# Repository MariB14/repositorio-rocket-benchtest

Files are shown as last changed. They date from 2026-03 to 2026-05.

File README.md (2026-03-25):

# Bench test stand "Maria"
## Objective
Design and manufacture of an instrument for measuring propulsion parameters for rocket motor class H to K with short funds and accesible materials.

## Keywords
* "Rocket motor testing"
* "Low-cost instrumentation"
* "Thrust measurement"
* "Truss analysis"
* "Pressure measurement"

## Particular objectives
* Restrictions of desired parameters to measure (maximum and minimums)
* Statistic sounding and research
* Cost analysis of material and sensors 
* Sensors involved and individual test
* Data logging of parameters individually
* Fusion of sensors and data sampling coupling of frequency
* Data logging fusion
* Power electronics of data logging and sensing
* Strucutral analysis proposal in function of restrictions
* Conceptual design and materials designation
* In-depth design of benchtest 
* Assembly and manufacturing considerations
* Quality control across manufacture
* Process sheet of manufacturing
* Quality assurance of manufacture
* Operations sheet procedure
* Redaction of Manual Of Use

## Research websites
* https://www.sciencedirect.com/
* https://link.springer.com/
* https://onlinelibrary.wiley.com/
* https://iopscience.iop.org/journalList
* https://www.ieee.org/
* https://www.tandfonline.com/
* https://pubs.acs.org/
* https://www.aps.org/

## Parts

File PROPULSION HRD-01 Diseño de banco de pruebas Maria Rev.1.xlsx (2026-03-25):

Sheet: Overview
 |  | (Materials selection in mechanical design, pp 12)
Design process for the structural components of the Rocket Bench stand |  |  | Concepto
 |  |  | Maxima carga de 300 kg en el eje horizontal (x)
1. Exhaustive analysis of loads |  |  | Viabilidad de lectura de perturbaciones en los tres ejes (x,y,z)
 | a. Permanent loads |  | Referencias | https://www.researchgate.net/publication/323685633_Design_and_Implementation_of_a_Thrust_Vector_Control_TVC_Test_System
 | b. Variable loads |  | Historial de proyectos similares
2. Overview of materials |  |  | Transportable maximo 20kg por ensamble completo sin motor
 | a. Characteristics for tension, compresion and flexion |  | Restriccion de costo $1,500 MXN
 | b. Variable and static loads capabilities |  | Elevado margen de seguridad (s.f. 2 - 3)
 | c. Corrosion and termal properties |  | Diseño por funcionalidad y analisis de cargas y apoyos
3. Predimension process taking into account step 2 and step 3 |  |  | Diseño de nodos para analisis de truss/armadura a maxima carga de medicion (300kg)
 | a. Design process |  | y perturbaciones del 20% de la maxima carga, demostracion de porcentaje en hoja de
 | b. Loads overview |  | armadura.
 | c. Materials asignation due to loads and geometry
 | d. Aesthetics
4. Structural analysis
 | a. Known materials properties
 | b. Loads conditions
 | c. Standards and normative
5. Simulations
 | a. FEM
 | b. Vibrations and fatigue
6. Drawings and tolerances
7. Tracking of structure, due to failure when it's used
8. Quality assurance
 | a. Calendar of use, manual register

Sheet: PTR base data
PTR cuadrado (Perfil Tubular Rectangular) | Calibre | Espesor (in) | Largo | Pieza x paquete | kg/m | Norma | Referencias de normas
1/2″ x 1/2″ | 20 | 0.036 | 6 | 231 | 0.34 | A513 | ASTM A513 | https://www.materiales.gelsonluz.com/2020/09/astm-a513-propiedades-mecanicas.html | A500B | ASTM A500 Grade B Specifications | American Standard Steel Products (nan-steel.com) (https://www.nan-steel.com/news/astm-a500-grade-b.html)
 | 18 | 0.048 | 6 | 231 | 0.44 | A513
5/8″ x 5/8″ | 20 | 0.036 | 6 | 252 | 0.43 | A513 | Referencia | PTR - Perfiles estructurales (fortacero.com) (https://www.fortacero.com/cat_ptr/)
 | 18 | 0.048 | 6 | 252 | 0.56 | A513
3/4″ x 3/4″ | 20 | 0.036 | 6 | 121 | 0.52 | A513
 | 18 | 0.048 | 6 | 121 | 0.68 | A513
 | 16 | 0.06 | 6 | 121 | 0.84 | A513
 | 14 | 0.075 | 6 | 121 | 1.02 | A513
1″ x 1″ | 20 | 0.036 | 6 | 100 | 0.7 | A513
 | 18 | 0.048 | 6 | 100 | 0.92 | A513
 | 16 | 0.06 | 6 | 100 | 1.14 | A513
 | 14 | 0.075 | 6 | 100 | 1.4 | A513
 | 13 | 0.09 | 6 | 100 | 1.65 | A513
 | 12 | 0.105 | 6 | 100 | 1.9 | A513
 | 11 | 0.12 | 6 | 100 | 1.94 | A500°B
 | 10 | 0.135 | 6 | 100 | 2.12 | A500°B
1 1/4″ x 1 1/4″ | 20 | 0.036 | 6 | 81 | 0.88 | A513
 | 18 | 0.0485 | 6 | 81 | 1.16 | A513
 | 16 | 0.06 | 6 | 100 | 1.44 | A513
 | 14 | 0.075 | 6 | 100 | 1.78 | A513
 | 12 | 0.105 | 6 | 100 | 2.42 | A513
1 1/2″ x 1 1/2″ | 20 | 0.036 | 6 | 49 | 1.06 | A513
 | 18 | 0.048 | 6 | 49 | 1.4 | A513
 | 16 | 0.06 | 6 | 100 | 1.74 | A513
 | 14 | 0.075 | 6 | 64 | 2.15 | A513
 | 12 | 0.105 | 6 | 64 | 2.95 | A513
 | 9 | 0.15 | 6 | 64 | 3.79 | A500°B
2″ x 2″ | 18 | 0.048 | 6 | 64 | 1.89 | A513
 | 14 | 0.075 | 6 | 64 | 2.91 | A513
 | 12 | 0.105 | 6 | 64 | 4.01 | A513
 | 10 | 0.135 | 6 | 64 | 4.84 | A500°B
 | 9 | 0.15 | 6 | 64 | 5.31 | A513
2 1/2″ x 2 1/2″ | 14 | 0.075 | 6 | 42 | 3.67 | A513
 | 11 | 0.12 | 6 | 36 | 5.57 | A500°B
 | 7 | 0.18 | 6.1 | 36 | 8.34 | A500°B
 | 1/4″ | 0.25 | 6.1 | 36 | 10.57 | A500°B
3″ x 3″ | 14 | 0.075 | 6 | 42 | 4.42 | A513
 | 11 | 0.12 | 6.10/ 12.20 | 36 | 6.78 | A500°B
 | 9 | 0.15 | 6.1 | 25 | 8.33 | A500°B
 | 7 | 0.18 | 6.1 | 25 | 10.24 | A500°B
 | 1/4″ | 0.25 | 6.10/ 12.20 | 25 | 13.1 | A500°B
3 1/2″ x 3 1/2″ | 11 | 0.12 | 6.1 | 36 | 7.99 | A500°B
 | 9 | 0.15 | 6.1 | 25 | 9.85 | A500°B
 | 7 | 0.18 | 6.1 | 25 | 12.14 | A500°B
 | 1/4″ | 0.25 | 6.10/12.20 | 16 | 15.63 | A500°B
4″ x 4″ | 14 | 0.075 | 6 | 30 | 5.93 | A513
 | 1/8″ | 0.125 | 6.10/12.20 | 30 | 9.21 | A500°B
 | 9 | 0.15 | 6.1 | 25 | 11.36 | A500°B
 | 3/16″ | 0.187 | 6.10/12.20 | 25 | 14.04 | A500°B
 | 1/4″ | 0.25 | 6.10/ 12.20 | 16 | 18.16 | A500°B
5″ x 5″ | 1/8″ | 0.125 | 6.10/12.20 | 20 | 11.63 | A500°B
 | 3/16″ | 0.187 | 6.10/12.20 | 16 | 18.96 | A500°B
 | 1/4″ | 0.25 | 6.10/12.20 | 12 | 23.22 | A500°B
PTR rectangular | Calibre | Espesor (in) | Largo | Pieza x paquete | kg/m | Norma
1″ x1/2″ | 18 | 0.048 | 6 | 120 | 0.68 | A513
1 1/4″ x 3/4″ | 20 | 0.036 | 6 | 99 | 0.7 | A513
 | 18 | 0.048 | 6 | 99 | 0.92 | A513
1 1/2″ x 1/2″ | 20 | 0.036 | 6 | 98 | 0.7 | A513
 | 18 | 0.048 | 6 | 98 | 0.92 | A513
1/2″ x 1″ | 20 | 0.036 | 6 | 84 | 0.88 | A513
 | 18 | 0.048 | 6 | 84 | 1.16 | A513
 | 16 | 0.06 | 6 | 100 | 1.44 | A513
 | 14 | 0.075 | 6 | 84 | 1.78 | A513
 | 11 | 0.12 | 6 | 63 | 2.55 | A513
1 3/4″» x 3/4″ | 20 | 0.036 | 6 | 84 | 0.88 | A513
 | 18 | 0.048 | 6 | 84 | 1.16 | A513
2″ x 1″ | 20 | 0.036 | 6 | 50 | 1.06 | A513
 | 18 | 0.048 | 6 | 50 | 1.4 | A513
 | 14 | 0.075 | 6 | 80 | 2.15 | A513
 | 11 | 0.12 | 6 | 80 | 3.15 | A500°B
2 1/4″ x 3/4″ | 20 | 0.036 | 6 | 55 | 1.06 | A513
 | 18 | 0.048 | 6 | 55 | 1.4 | A513
2 1/2″ x 1 1/4″ | 20 | 0.075 | 6 | 54 | 1.34 | A513
 | 18 | 0.075 | 6 | 54 | 1.77 | A513
 | 14 | 0.075 | 6 | – | – | A513
2 1/2″» x 1 1/2″ | 14 | 0.075 | 6 | 48 | 2.91 | A513
3″ x 1″ | 18 | 0.048 | 6 | 48 | 1.89 | A513
 | 16 | 0.06 | 6 | 48 | 2.35 | A513
 | 14 | 0.075 | 6 | 48 | 2.91 | A513
 | 11 | 0.12 | 6 | 48 | 4.36 | A513
 | 10 | 0.135 | 6 | 48 |  | A513
3″ x 1 1/2″ | 20 | 0.036 | 6 | 48 | 1.61 | A513
 | 18 | 0.048 | 6 | 70 | 2.13 | A513
 | 14 | 0.075 | 6 | 70 | 3.29 | A513
 | 11 | 0.12 | 6 | 70 | 4.9 | A500°B
3″ x 2″ | 14 | 0.075 | 6 | 49 | 3.67 | A513
 | 11 | 0.12 | 6 | 42 | 5.57 | A500°B
 | 10 | 0.135 | 6 | 42 | 6.2 | A500°B
 | 7 | 0.18 | 6.1 | 36 | 8.34 | A500°B
 | 1/4″ | 0.25 | 6.1 | 36 | 10.57 | A500°B
4″ x 1 1/2″ | 14 | 0.075 | 6 | 35 | 4.04 | A513
4″ x 2″ | 14 | 0.075 | 6.1 | 40 | 4.42 | A513
 | 11 | 0.12 | 6.1 | 32 | 6.78 | A500°B
 | 9 | 0.15 | 6.1 | 32 | 8.33 | A500°B
 | 7 | 0.18 | 6.1 | 28 | 10.24 | A500°B
 | 1/4″ | 0.25 | 6.10/ 12.20 | 20 | 13.13 | A500°B
4″ x 3″ | 14 | 0.075 | 6 | 40 | 5.18 | A513
 | 11 | 0.12 | 6.1 | 30 | 7.99 | A500°B
 | 9 | 0.15 | 6.10/ 12.20 | 25 | 9.85 | A500°B
 | 7 | 0.18 | 6.1 | 20 | 12.14 | A500°B
 | 1/4″ | 0.25 | 6.10/12.20 | 16 | 15.63 | A500°B
5″ x 2″ | 11 | 0.12 | 6.1 | 20 | 7.99 | A500°B
 | 7 | 0.18 | 6.1 | 20 | 12.14 | A500°B
5″ x 3″ | 14 | 0.075 | 6 | 35 | 5.93 | A513
 | 1/8″ | 0.125 | 6.10/ 12.20 | 35 | 9.21 | A500°B
 | 3/16″ | 0.187 | 6.10/ 12.20 | 24 | 14.03 | A500°B
 | 1/4″ | 0.25 | 6.10/ 12.20 | 18 | 18.16 | A500°B
6″ x 2″ | 14 | 0.075 | 6 | 16 | 5.93 | A513
 | 1/8″ | 0.125 | 6.10/ 12.20 | 16 | 9.21 | A500°B
 | 3/16″ | 0.187 | 6.10/ 12.20 | 16 | 14.03 | A500°B
 | 1/4″ | 0.25 | 6.10/ 12.20 | 16 | 18.16 | A500°B
6″ x 4″ | 1/8″ | 0.125 | 6.10/ 12.20 | 20 | 11.63 | A500°B
 | 3/16″ | 0.187 | 6.10/12.20 | 20 | 17.85 | A500°B
 | 1/4″ | 0.25 | 6.10/ 12.20 | 12 | 23.22 | A500°B
8″ x 3″ | 1/8″ | 0.125 | 12.2 | 12 | 13.61 | A500°B
 | 3/16″ | 0.187 | 12.2 | 12 | 20 | A500°B

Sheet: Example
Evaluar condiciones de equilibrio |  |  |  | Reacciones en apoyos |  | Sumatoria en D
Sum Fx=0 |  | Sum Mx=0 |  | Fx= Ax + Bx + Dx = 0 |  | Md= Mfa + Mfb + Mfc
Sum Fy=0 |  | Sum My=0 |  | Fy= By + Dy - 400 |  | Mfa = R X Ax
Sum Fz=0 |  |  |  | Fz= Dz=0 |  | Mfa= (10j + 7k)x Axi
 |  |  |  | Dos ecuaciones 5 incognitas |  | Mfa= -10Axk + 7Axj
 |  |  |  | nos apoyamos con momentos
 |  |  |  |  |  | Mfb = R x Bx + R x By
 |  |  |  | Momentos |  | Mfb= 14k x Bxi + 14k x Byj
 |  |  |  | Mx= -14By + 2800 |  | Mfb = 14Bxj - 14Byi
 |  |  |  | My= 7Ax + 14Bx
 |  |  |  | Mz= -10Ax - 9600 |  | Mfc= Rx-400j
 |  |  |  |  |  | Mfc= (24i + 7k) x -400j
 |  |  |  |  |  | Mfc= -9600k + 2800i
Sistema de ecuaciones |  |  | Donde
Ax + Bx + Dx= 0 |  |  | Ax= -9600/10
By + Dy = 400 |  |  | Ax | -960
(-14)By = -2800
7Ax + 14Bx = 0 |  |  | By=2800/14
(-10)Ax = 9600 |  |  | By | 200
Despejando para Bx |  |  | Despejando de segunda ecuacion
Bx | 480 |  | Dy | 200
 |  |  | Dx | 480
Calcular ecuaciones en cada nodo
En nodo B
Evaluamos un sistema de coordenadas para cada nodo
A(0,10,0)
B(0,0,7)
C(24,0,0)
D(0,0,-7)
Calculamos el vector longitud del elemento AB |  |  |  |  | Se realiza lo mismo para cada seccion de los nodos
AB= 0i + 10j -7k |  |  |  |  | F_BC =0.96|Fbc|i- 0.28|Fbc|k
|AB|= raiz(10^2 + (-7)^2) |  |  |  |  | F_BD= -|Fbd|k
|AB|= | 12.20655562
Vector unitario= |  | elemento sobre longitud
u= 10/12.2 j - 7/12.2k
F_AB= |F_AB|unitario
F_AB=0.82|Fab|j - 0.58|Fab|k
Sumatorias en los ejes x,y,z
Fx | 0.96|Fbc|i + 480 = 0
Fy | 0.82|Fab|j +200 = 0
Fz | (-0.58)|Fab|k - |Fbd|k - 0.28|Fbc|k = 0
Fab= -224lb C
Fbc= -500lb C
Fbd= 280lb T

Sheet: Truss design
 |  |  |  |  |  |  | Suponiendo que al dar inicio a la prueba, ya sea porque el motor fue mal acomodado o perturbaciones externas
 |  |  |  |  |  |  | genera ya sea una deformacion o un movimiento del motor de 3 grados, es decir el punto donde el empuje es generado,
 |  |  |  |  |  |  | probocara un cambio en la lectura de las reacciones. Las celdas de los ejes x y y deben soportar esos posibles accidentes
 |  |  |  |  |  |  | o perturbaciones
 |  |  |  |  |  |  | De | Negando la friccion de la union del motor al banco para la condicion de empotramiento
 |  |  |  |  |  |  | Ty + Fsy + Fay+ Fy = 0
 |  |  |  |  |  |  | aFay + LFy = 0
 |  |  |  |  |  |  | Ty + Fay + Fy = 0 | Acordando que todo el empuje es dirigido en la direccion a la que la celda de carga izquierda
 |  |  |  |  |  |  |  | es posicionada, es decir debido a una mala colocacion del motor el vector de fuerza
 |  |  |  |  |  |  |  | debido al gradiente nuevo de posicion que tomo es ejercido en la posicion de
 |  |  |  |  |  |  |  | esa celda en especifico
 |  |  |  |  |  |  |  |  | En el plano ay-x donde se esta ejerciendo esta nueva
 |  |  |  |  |  |  |  |  |  | Fy | 26.14672282 | kg | 8.715574275%
 |  |  |  |  |  |  |  |  |  | Hacemos que esta sea la carga
 |  |  |  |  |  |  |  |  |  | maxima que operara Fleft o Fright
 |  |  |  |  |  |  |  |  |  | Sin embargo no esta demas ampliar
 |  |  |  |  |  |  |  |  |  | al 20% el rango considerable
Las ecuaciones en cada eje son las siguientes: |  | Las medidas de a y L es la respectiva ubicacion de donde estan ubicadas las celdas en hexagono y el largo total del motor
plano x-y | Momentos | a= | 0.3 | m | L= | 0.45 | m
Sum Fx=0 | Sum My=0 | Donde el los momentos de Msy y Msz tienden a ser pequeños que pueden ser ignorados
Tx + Fax - Fx= 0 | Msy+aFay + LFy =0 | La variable Tx es la lectura leida en la celda de carga principal
Sum Fy= 0 |  | Ty y Tz son las reacciones debido a la condicion de "empotramiento" del motor que actua como una viga para este analisis
Ty + Fsy + Fay + Fy= 0
 |  | Las reacciones por friccion son:
plano x-z | Momentos | Fax donde esta rozando el motor con las celdas de carga en forma hexagonal
Sum Fz=0 | Sum Mz=0 | Fsz y Fsy son las reacciones debido a la union con el motor para la condicion de empotramiento
Tz+Fsz+Faz-G+Fz=0 | Msz- bG + aFaz + LFz = 0
Las fuerzas laterales de Faz y Fay son calculadas de la siguiente manera:
Fay= -(Fleftcos30 - Frightcos30)
Faz= -(Frightsin30 + Fleftsin30 - Ftop)

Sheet: Truss design 2.0
Truss by points |  |  |  | Input cell
Back support
Analysis by member of truss (tension or compression)
Length of member | 20 | mm | 0.787 | in
a | 25.4 | mm | 1 | in
b | 25.4 | mm | 1 | in
Caliber (thick.) | 2.381 | mm | 0.09 | in
Trans area | 219.254 | mm2
x-z
Back support group | x | z
1 | 0 | 0
 | 0 | 20
2 | 0 | 20
 | 20 | 20
3 | 20 | 20
 | 20 | 0
4 | 20 | 0
 | 0 | 0
5 | 20 | 20
 | 0 | 0
 |  |  |  | in
Short members | 20 | mm | 0.7874015748 | in
Large member | 40 | mm | 1.57480315
SRM base | x | z | x | z
1.1 | 0 | 0 | 20 | 0
 | 20 | 0 | 40 | 0
2.1 | 20 | 0 | 40 | 0
 | 40 | 0 | 60 | 0
3.1 | 40 | 0 | 60 | 0
 | 80 | 0 | 100 | 0
4.1 | 80 | 0 | 100 | 0
 | 120 | 0 | 140 | 0
 |  |  |  |  | Dimension de "B" es f(diametro) |  |  | Dimension de "A"
Dimensiones de caja de banco |  |  |  |  | tomando los datos de abajo: |  |  | la dimension de "A" depende del largo de la viga empotrada la "azul"
A
B |  |  |  |  | la dimension "B" debe ser min 98 |  |  | Dimension "VIGA"
C |  |  |  |  | la dimension "B" puede ser 2*B anterior |  |  | simulacion y analisis teorico
viga
ranura |  |  |  |  | la dimension de "C" = "b" |  |  | ranura depende de que tanto se va mover
r1 |  |  |  |  |  |  |  | r1 y r0 dependen de donde se va localizar esa ranura
r0
Dimensiones de plano de banco
a |  |  |  |  | Dimensionamiento de "a" |  |  |  | dimension "b" f(diametro)
b |  |  |  |  | 1. Nuestro motor | 30cm |  |  | 35mm
c |  |  |  |  | 2. motores h | 124 | 365 | MM | 29 | 38
 |  |  |  |  | 3. motores i | 69 | 367 | mm | 29 | 54
 |  |  |  |  | 4. jota | 218 | 584 | mm | 38 | 54
 |  |  |  |  | 5. ka | 260 | 728 | mm | 54 | 98
 |  |  |  |  | a tiene que ser min de 72.8 cm |  |  |  | la dimension b min es de 98 mm
 |  |  |  |  |  |  |  |  | que b tiene que ser 2b
 |  |  |  |  |  |  |  |  | b puede ser 3 el min de b
 |  |  |  |  | la dimension "c" depende de las simulaciones
 |  |  |  |  | 1 probar la sim con el empuje mas grande (motor K) y ver dos casos
 |  |  |  |  | con la viga de c | si hay un cambio muy notorio, se deja la viga y se juega con la distancia donde se solda
 |  |  |  |  | sin la viga de c

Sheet: Instrumentation
Load cell reference
Sensor de pesaje de dos vías tipo S, 100kg, 200kg, 300kg, 500kg, 2000kg, 1 tonelada, 1,5 toneladas, 2 toneladas, 1T, sensor de presión de tracción, sensor de peso, celda de carga - AliExpress (https://es.aliexpress.com/item/1005006070642588.html)
Load cell general info
#VALUE! | Interested load cell
 | RAYTEI-Sensores de transductor de carga de compresión de tensión en miniatura, células de carga en línea de alta precisión, 10kg, 15kg, 20kg, 30kg, 50kg, 100kg - AliExpress 502 (https://es.aliexpress.com/item/1005006236153559.html?scm_id=1007.40000.327270.0&scm-url=1007.40000.327270.0)
 | More interesting load cell
 | DYLF-102 de aleación de acero, célula de carga redonda de compresión, 50kg, 80kg, 500kg, 1t, 3t, 5t, 50t, 100t, 500t - AliExpress 502 (https://es.aliexpress.com/item/1005006732452379.html?scm_id=1007.40000.326746.0&scm-url=1007.40000.326746.0)
 | ADC selection
 | sex
ADC
Módulo de Conversión de Analógico a Digital Placa de Adquisición de Señal ADC de Alta Precisión de 8 Canales Y 24 Bits Convierta Señales Analógicas en Señales Digitales : Amazon.com.mx: Industria, Empresas y Ciencia (https://www.amazon.com.mx/Conversi%C3%B3n-Anal%C3%B3gico-Adquisici%C3%B3n-Precisi%C3%B3n-Anal%C3%B3gicas/dp/B099KR3ZH2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)

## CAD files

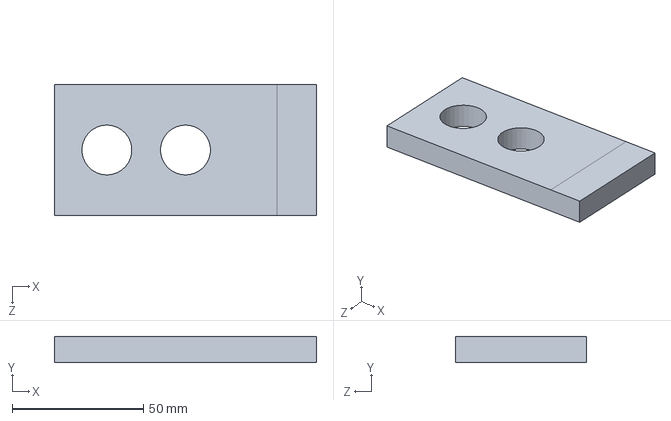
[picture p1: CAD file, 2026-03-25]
FEA sample tests/00 Assem sim2.SLDASM
100.0 x 10.00 x 50.0 mm

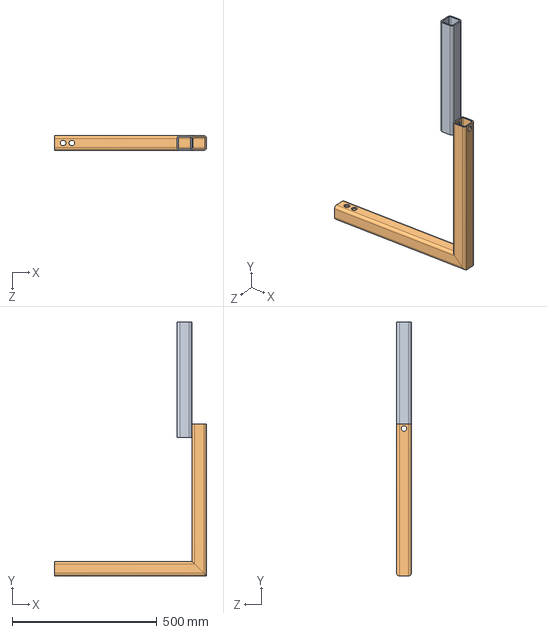
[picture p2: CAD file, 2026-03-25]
FEA sample tests/00 Assem sim1.SLDASM
525.4 x 877.8 x 50.8 mm
codo de simulacion
extension de simulacion

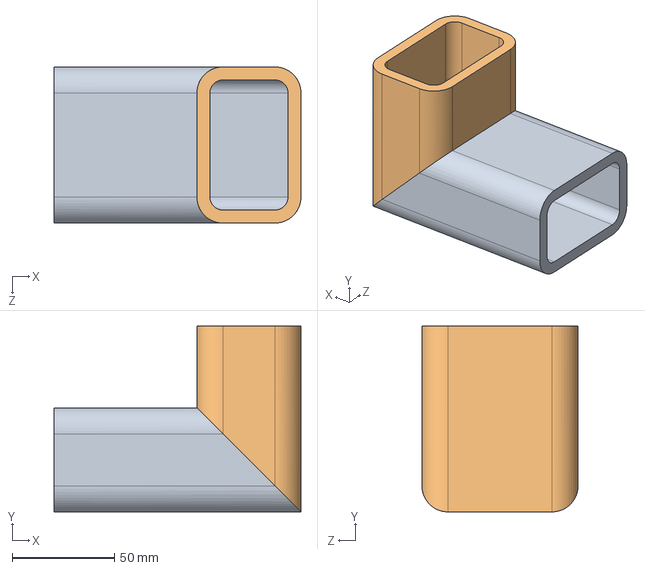
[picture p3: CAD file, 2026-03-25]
FEA sample tests/L para sim.STEP
120.5 x 90.7 x 76.2 mm

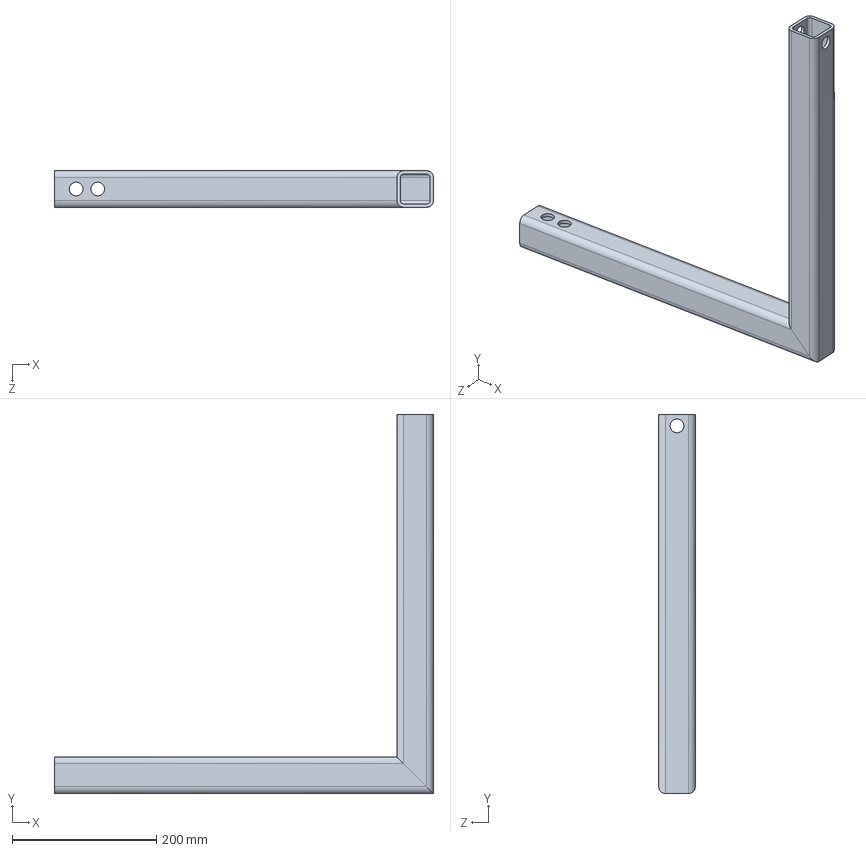
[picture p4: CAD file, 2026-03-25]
FEA sample tests/codo de simulacion.SLDPRT
525.4 x 525.4 x 50.8 mm

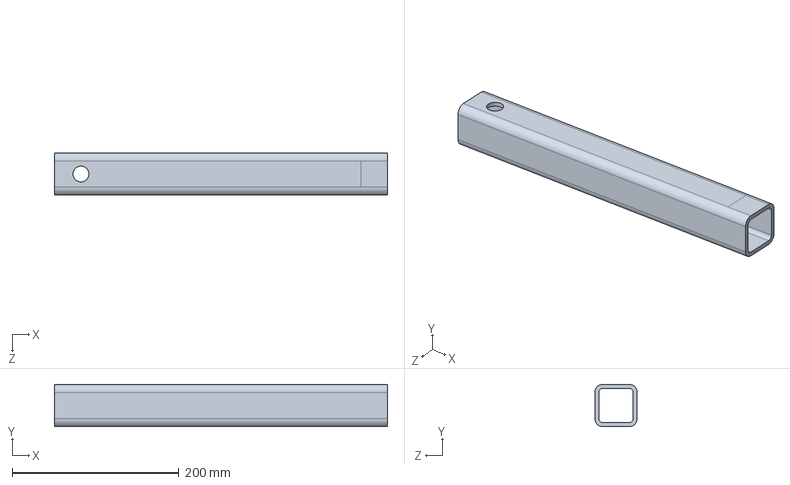
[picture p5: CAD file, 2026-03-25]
FEA sample tests/extension de simulacion.SLDPRT
400.0 x 50.8 x 50.8 mm

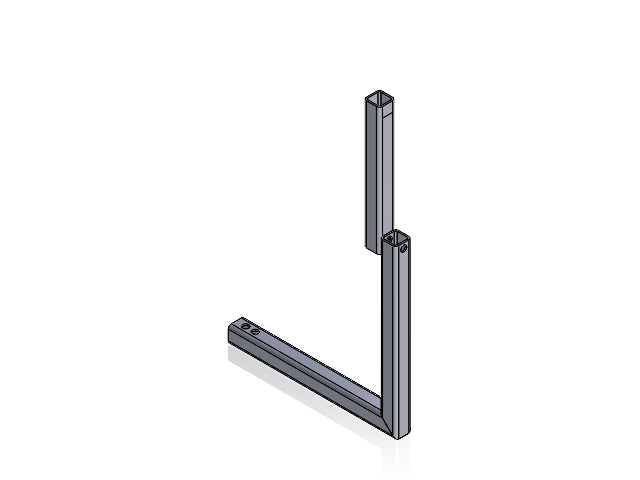
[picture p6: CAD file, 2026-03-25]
FEA sample tests/01 Assem sim1 STEP.SLDASM
codo de simulacion STEP.step
extension de simulacion STEP.step

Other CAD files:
FEA sample tests/extension de simulacion STEP.STEP
FEA sample tests/codo de simulacion STEP.STEP
FEA sample tests/placa fijada.SLDPRT
FEA sample tests/L para sim.SLDPRT
FEA sample tests/codo de simulacion STEP.SLDPRT

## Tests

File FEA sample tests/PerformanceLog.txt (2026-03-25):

Number of Contacts: 1
Number of contact data: 234

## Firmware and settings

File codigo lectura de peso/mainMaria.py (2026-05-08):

#!/usr/bin/python3
# -*- coding:utf-8 -*-

import spidev, RPi.GPIO as GPIO, time, sys, termios, tty, select, csv, os
from collections import deque
import math
import json

# ==============================
# CONFIGURACIÓN DE PINES / SPI
# ==============================
RST_PIN, CS_PIN, DRDY_PIN = 18, 22, 17
RELAY_PIN = 26 # Pin para control de relay (ignición)

SPI = spidev.SpiDev(0, 0)

def digital_write(pin, val): GPIO.output(pin, val)
def digital_read(pin): return GPIO.input(pin)
def delay_ms(ms): time.sleep(ms/1000.0)
def spi_writebyte(data): SPI.writebytes(data)
def spi_readbytes(n): return SPI.readbytes(n)

def module_init():
    GPIO.setmode(GPIO.BCM)
    GPIO.setwarnings(False)
    GPIO.setup(RST_PIN, GPIO.OUT)
    GPIO.setup(CS_PIN, GPIO.OUT)
    GPIO.setup(DRDY_PIN, GPIO.IN, pull_up_down=GPIO.PUD_UP)
    GPIO.setup(RELAY_PIN, GPIO.OUT, initial=GPIO.LOW)
    print(f"🔧 RELAY_PIN {RELAY_PIN} configurado como OUTPUT")
    SPI.max_speed_hz, SPI.mode = 20000, 0b01
    return 0

# ==============================
# ADS1256
# ==============================
ADS1256_GAIN_E = {1:0, 2:1, 4:2, 8:3, 16:4, 32:5, 64:6}
ADS1256_DRATE_E = {'30SPS':0xF0, '60SPS':0xF1, '100SPS':0x82, '500SPS':0x85}
REG_E = {'REG_MUX':1,'REG_ADCON':2,'REG_DRATE':3}
CMD = {'CMD_WREG':0x50,'CMD_RDATA':0x01}

class ADS1256:
    def __init__(self): 
        self.rst_pin, self.cs_pin, self.drdy_pin = RST_PIN, CS_PIN, DRDY_PIN
    
    def reset(self):
        digital_write(self.rst_pin,1); delay_ms(50)
        digital_write(self.rst_pin,0); delay_ms(50)
        digital_write(self.rst_pin,1); delay_ms(50)
    
    def write_reg(self, reg, data):
        digital_write(self.cs_pin,0)
        spi_writebyte([CMD['CMD_WREG']|reg,0,data])
        digital_write(self.cs_pin,1)
    
    def wait_drdy(self): 
        timeout = time.time() + 1.0
        while digital_read(self.drdy_pin)==1:
            if time.time() > timeout:
                raise Exception("DRDY timeout")
            pass
    
    def config(self, gain, drate):
        self.wait_drdy()
        digital_write(self.cs_pin,0)
        spi_writebyte([CMD['CMD_WREG']|0,0x03])
        spi_writebyte([0x01,0x08,ADS1256_GAIN_E[gain],drate])
        digital_write(self.cs_pin,1)
        delay_ms(1)
    
    def set_diff_ch(self): 
        self.write_reg(REG_E['REG_MUX'], (0<<4)|1)  # AIN0-AIN1
    
    def init(self, gain, drate):
        if module_init()!=0: return -1
        self.reset()
        self.config(gain, drate)
        return 0
    
    def read_data(self):
        self.wait_drdy()
        digital_write(self.cs_pin,0)
        spi_writebyte([CMD['CMD_RDATA']])
        b=spi_readbytes(3)
        digital_write(self.cs_pin,1)
        raw=(b[0]<<16)|(b[1]<<8)|b[2]
        if raw & 0x800000: raw -= 0x1000000
        return raw

# ==============================
# CONFIGURACIÓN Y CALIBRACIÓN
# ==============================
CONFIG_FILE = "thrust_config.json"

def load_config():
    """Carga configuración guardada o usa defaults"""
    default = {
        "GAIN": 16,
        "DRATE": "100SPS",
        "VREF": 5.0,
        "calibration_factor": 1.0,  # kgf = mV * factor
        "raw_zero": 0
    }
    if os.path.exists(CONFIG_FILE):
        try:
            with open(CONFIG_FILE, 'r') as f:
                return json.load(f)
        except:
            return default
    return default

def save_config(config):
    """Guarda configuración actual"""
    with open(CONFIG_FILE, 'w') as f:
        json.dump(config, f, indent=2)

# ==============================
# FILTROS
# ==============================
def calc_alpha(sps, tau=0.03):
    """Calcula alpha para filtro EMA (tau=30ms default)"""
    Ts = 1.0/sps
    return 1 - math.exp(-Ts/tau)

def median3(buf):
    """Filtro mediana de 3 muestras"""
    if len(buf) < 3: return buf[-1]
    a,b,c = list(buf)[-3:]
    return sorted([a,b,c])[1]

def code_to_mV(delta, gain, vref, code_fs=0x7fffff):
    """Convierte código ADC a milivoltios"""
    return (delta * (vref/gain) / code_fs) * 1000.0

# ==============================
# UTILIDADES TECLADO
# ==============================
def set_cbreak():
    fd=sys.stdin.fileno()
    st=termios.tcgetattr(fd)
    tty.setcbreak(fd)
    return fd,st

def restore_term(fd,st): 
    termios.tcsetattr(fd,termios.TCSADRAIN,st)

def kbhit(): 
    dr,_,_=select.select([sys.stdin],[],[],0)
    return dr!=[]

def getch(): 
    return sys.stdin.read(1)

def input_with_default(prompt, default):
    """Input con valor por defecto"""
    val = input(f"{prompt} [default: {default}]: ").strip()
    return val if val else str(default)

# ==============================
# MODO 1: CALIBRACIÓN
# ==============================
def modo_calibracion():
    """Menú de calibración"""
    print("\n" + "="*60)
    print("🔧 MODO CALIBRACIÓN")
    print("="*60)
    print("1. Calibración manual (pesos verticales)")
    print("2. Configurar parámetros (GAIN, SPS)")
    print("3. Calibración automática con pesos conocidos")
    print("4. Volver al menú principal")
    
    opcion = input("\nSelecciona opción: ").strip()
    
    if opcion == "1":
        calibracion_manual()
    elif opcion == "2":
        configurar_parametros()
    elif opcion == "3":
        calibracion_automatica()
    elif opcion == "4":
        return
    else:
        print("❌ Opción inválida")

def calibracion_manual():
    """Calibración manual con pesos conocidos"""
    config = load_config()
    
    print("\n" + "="*60)
    print("📏 CALIBRACIÓN MANUAL")
    print("="*60)
    print("Instrucciones:")
    print("1. Coloca el banco en posición VERTICAL")
    print("2. Coloca un peso conocido")
    print("3. El sistema calculará el factor de calibración")
    print("="*60)
    
    # Inicializar ADC
    adc = ADS1256()
    gain = config["GAIN"]
    drate = config["DRATE"]
    
    if adc.init(gain, ADS1256_DRATE_E[drate]) != 0:
        print("❌ Error inicializando ADC")
        return
    
    adc.set_diff_ch()
    
    # Tare inicial
    print("\n🔄 Realizando tare (sin peso)...")
    input("Presiona ENTER cuando esté sin peso...")
    N = 20
    raw_zero = sum(adc.read_data() for _ in range(N)) // N
    config["raw_zero"] = raw_zero
    print(f"✅ Tare establecido: raw = {raw_zero}")
    
    # Lectura con peso conocido
    print("\n⚖️  Coloca el peso conocido en posición vertical")
    peso_kg = float(input("Peso conocido (kg): "))
    input("Presiona ENTER cuando esté el peso colocado...")
    
    # Promediar lecturas
    print("📊 Promediando 50 lecturas...")
    readings = []
    for _ in range(50):
        adc.set_diff_ch()
        raw = adc.read_data()
        delta = raw - raw_zero
        mv = code_to_mV(delta, gain, config["VREF"])
        readings.append(mv)
        time.sleep(0.01)
    
    avg_mv = sum(readings) / len(readings)
    
    # Calcular factor
    if avg_mv != 0:
        calibration_factor = peso_kg / avg_mv
        config["calibration_factor"] = calibration_factor
        
        print(f"\n✅ Calibración completada:")
        print(f"   Voltaje promedio: {avg_mv:.3f} mV")
        print(f"   Peso conocido: {peso_kg} kg")
        print(f"   Factor calibración: {calibration_factor:.6f} kg/mV")
        
        save_config(config)
        print("\n💾 Configuración guardada")
    else:
        print("❌ Error: voltaje cero, verifica conexiones")
    
    input("\nPresiona ENTER para continuar...")

def configurar_parametros():
    """Configurar GAIN y SPS"""
    config = load_config()
    
    print("\n" + "="*60)
    print("⚙️  CONFIGURAR PARÁMETROS")
    print("="*60)
    print(f"Configuración actual:")
    print(f"  GAIN: {config['GAIN']}")
    print(f"  SPS: {config['DRATE']}")
    print(f"  Factor calibración: {config['calibration_factor']:.6f}")
    print("="*60)
    
    # GAIN
    print("\nGAIN disponibles: 1, 2, 4, 8, 16, 32, 64")
    gain_input = input_with_default("Nuevo GAIN", config["GAIN"])
    try:
        new_gain = int(gain_input)
        if new_gain in ADS1256_GAIN_E:
            config["GAIN"] = new_gain
        else:
            print("⚠️  GAIN inválido, manteniendo anterior")
    except:
        print("⚠️  Entrada inválida, manteniendo anterior")
    
    # SPS
    print("\nSPS disponibles: 30SPS, 60SPS, 100SPS, 500SPS")
    drate_input = input_with_default("Nuevo SPS", config["DRATE"])
    if drate_input in ADS1256_DRATE_E:
        config["DRATE"] = drate_input
    else:
        print("⚠️  SPS inválido, manteniendo anterior")
    
    save_config(config)
    print("\n✅ Parámetros guardados")
    input("\nPresiona ENTER para continuar...")

def calibracion_automatica():
    """Calibración automática con múltiples pesos"""
    config = load_config()
    
    print("\n" + "="*60)
    print("🤖 CALIBRACIÓN AUTOMÁTICA")
    print("="*60)
    print("Este proceso usará 3 pesos conocidos: 1kg, 10kg, 20kg")
    print("Coloca el banco en posición VERTICAL")
    print("="*60)
    
    pesos_conocidos = [1.0, 10.0, 20.0]  # kg
    
    # Inicializar ADC
    adc = ADS1256()
    gain = config["GAIN"]
    drate = config["DRATE"]
    
    if adc.init(gain, ADS1256_DRATE_E[drate]) != 0:
        print("❌ Error inicializando ADC")
        return
    
    adc.set_diff_ch()
    
    # Tare
    print("\n🔄 Realizando tare (sin peso)...")
    input("Presiona ENTER cuando esté sin peso...")
    N = 20
    raw_zero = sum(adc.read_data() for _ in range(N)) // N
    config["raw_zero"] = raw_zero
    print(f"✅ Tare: {raw_zero}")
    
    # Recolectar datos de calibración
    voltajes = []
    for peso in pesos_conocidos:
        print(f"\n⚖️  Coloca peso de {peso} kg")
        input("Presiona ENTER cuando esté colocado...")
        
        # Promediar
        readings = []
        for _ in range(30):
            adc.set_diff_ch()
            raw = adc.read_data()
            delta = raw - raw_zero
            mv = code_to_mV(delta, gain, config["VREF"])
            readings.append(mv)
            time.sleep(0.01)
        
        avg_mv = sum(readings) / len(readings)
        voltajes.append(avg_mv)
        print(f"   Voltaje promedio: {avg_mv:.3f} mV")
    
    # Regresión lineal simple (y = mx)
    # m = sum(x*y) / sum(x*x)
    sum_xy = sum(p * v for p, v in zip(pesos_conocidos, voltajes))
    sum_xx = sum(v * v for v in voltajes)
    
    if sum_xx != 0:
        calibration_factor = sum_xy / sum_xx
        config["calibration_factor"] = calibration_factor
        
        print(f"\n✅ Calibración completada:")
        print(f"   Factor: {calibration_factor:.6f} kg/mV")
        print(f"\n   Verificación:")
        for peso, voltaje in zip(pesos_conocidos, voltajes):
            estimado = voltaje * calibration_factor
            error = abs(estimado - peso) / peso * 100
            print(f"   {peso}kg → {voltaje:.2f}mV → {estimado:.2f}kg (error: {error:.1f}%)")
        
        save_config(config)
        print("\n💾 Configuración guardada")
    else:
        print("❌ Error en calibración")
    
    input("\nPresiona ENTER para continuar...")

# ==============================
# MODO 2: PRUEBA CON IGNICIÓN
# ==============================
def modo_prueba():
    """Modo de prueba con countdown e ignición"""
    config = load_config()
    
    print("\n" + "="*60)
    print("🚀 MODO PRUEBA - BANCO DE EMPUJE")
    print("="*60)
    
    # Parámetros de prueba
    print("\n⏱️  CONFIGURACIÓN DE TIEMPOS:")
    timer_ignicion = int(input_with_default("Tiempo ANTES de ignición (segundos)", 60))
    duracion_relay = int(input_with_default("Duración activación relay (segundos)", 30))
    duracion_total = int(input_with_default("Duración TOTAL de grabación (segundos)", 120))
    
    if timer_ignicion >= duracion_total:
        print("❌ Error: timer de ignición debe ser menor que duración total")
        input("\nPresiona ENTER para continuar...")
        return
    
    print(f"\n📋 RESUMEN:")
    print(f"   t=0s → Inicia grabación + countdown")
    print(f"   t={timer_ignicion}s → IGNICIÓN (relay ON por {duracion_relay}s)")
    print(f"   t={timer_ignicion + duracion_relay}s → RELAY OFF")
    print(f"   t={duracion_total}s → Fin de prueba")
    print(f"\n   GAIN: {config['GAIN']}")
    print(f"   SPS: {config['DRATE']}")
    print(f"   Factor calibración: {config['calibration_factor']:.6f} kg/mV")
    
    confirm = input("\n¿Iniciar prueba? (s/n): ").strip().lower()
    if confirm != 's':
        print("❌ Prueba cancelada")
        return
    
    # Inicializar ADC
    adc = ADS1256()
    gain = config["GAIN"]
    drate = config["DRATE"]
    vref = config["VREF"]
    calibration_factor = config["calibration_factor"]
    
    if adc.init(gain, ADS1256_DRATE_E[drate]) != 0:
        print("❌ Error inicializando ADC")
        return
    
    adc.set_diff_ch()
    
    # TEST MANUAL DEL RELAY
    print("\n🔧 TEST DEL RELAY:")
    print("Activando relay por 3 segundos...")
    GPIO.output(RELAY_PIN, GPIO.HIGH)
    print(f"Estado GPIO después de HIGH: {GPIO.input(RELAY_PIN)}")
    time.sleep(3)
    GPIO.output(RELAY_PIN, GPIO.LOW)
    print(f"Estado GPIO después de LOW: {GPIO.input(RELAY_PIN)}")
    test_ok = input("¿Se activó el relay correctamente? (s/n): ").strip().lower()
    
    if test_ok != 's':
        print("⚠️  ADVERTENCIA: El relay no funcionó en el test.")
        print("Verifica las conexiones antes de continuar.")
        continuar = input("¿Continuar de todas formas? (s/n): ").strip().lower()
        if continuar != 's':
            return
    
    # Usar tare guardado o hacer uno nuevo
    usar_tare = input("\n¿Usar tare guardado? (s/n): ").strip().lower()
    if usar_tare == 's':
        raw_zero = config["raw_zero"]
        print(f"✅ Usando tare guardado: {raw_zero}")
    else:
        print("🔄 Realizando nuevo tare...")
        N = 20
        raw_zero = sum(adc.read_data() for _ in range(N)) // N
        config["raw_zero"] = raw_zero
        save_config(config)
        print(f"✅ Nuevo tare: {raw_zero}")
    
    # Setup filtros
    sps_val = int(drate.replace("SPS", ""))
    alpha = calc_alpha(sps_val)
    history = deque(maxlen=3)
    ema_val = 0
    
    # Iniciar prueba
    print("\n" + "="*60)
    print("🔥 INICIANDO PRUEBA EN 3 SEGUNDOS...")
    print("="*60)
    time.sleep(3)
    
    relay_activado = False
    relay_apagado = False  # Nueva bandera para evitar múltiples prints
    
    timestamp = time.strftime("%Y%m%d_%H%M%S")
    filename = f"thrust_test_{timestamp}.csv"
    
    try:
        with open(filename, "w", newline="") as f:
            writer = csv.writer(f)
            writer.writerow(["tiempo_s", "raw", "delta", "voltaje_mV", 
                           "fuerza_kgf", "relay_status", "GAIN", "SPS"])
            
            start_time = time.time()
            
            print("\n⏺️  GRABANDO DATOS...")
            print("Presiona Ctrl+C para detener manualmente\n")
            
            while True:
                t = time.time() - start_time
                
                # Verificar si terminar
                if t >= duracion_total:
                    break
                
                # CONTROL DEL RELAY - VERSIÓN CORREGIDA
                tiempo_fin_relay = timer_ignicion + duracion_relay
                
                if t >= timer_ignicion and t < tiempo_fin_relay:
                    # Periodo de activación
                    if not relay_activado:
                        print(f"\n{'🔥'*20}")
                        print(f"⚡ IGNICIÓN ACTIVADA - t={t:.2f}s")
                        print(f"⚡ Relay permanecerá activo hasta t={tiempo_fin_relay:.2f}s")
                        print(f"{'🔥'*20}\n")
                        relay_activado = True
                    GPIO.output(RELAY_PIN, GPIO.LOW)
                else:
                    # Fuera del periodo de activación
                    if relay_activado and not relay_apagado:
                        GPIO.output(RELAY_PIN, GPIO.HIGH)
                        print(f"\n{'⚠️ '*20}")
                        print(f"⚠️  RELAY APAGADO - t={t:.2f}s")
                        print(f"{'⚠️ '*20}\n")
                        relay_apagado = True
                    elif not relay_activado:
                        GPIO.output(RELAY_PIN, GPIO.HIGH)
                
                # Leer datos
                adc.set_diff_ch()
                raw = adc.read_data()
                delta = raw - raw_zero
                mv = code_to_mV(delta, gain, vref)
                
                # Filtros
                history.append(mv)
                mv_med = median3(history)
                ema_val = alpha * mv_med + (1 - alpha) * ema_val
                
                # Convertir a fuerza
                fuerza_kgf = ema_val * calibration_factor
                
                # Estado relay
                relay_status = "ON" if GPIO.input(RELAY_PIN) == GPIO.LOW else "OFF"
                
                # Guardar y mostrar
                writer.writerow([f"{t:.3f}", raw, delta, f"{ema_val:.6f}", 
                               f"{fuerza_kgf:.6f}", relay_status, gain, drate])
                
                # Display con countdown visual
                if t < timer_ignicion:
                    countdown = timer_ignicion - t
          
                    print(f"⏳ t={t:6.2f}s | COUNTDOWN: {countdown:5.1f}s | "
                          f"V={ema_val:8.3f}mV | F={fuerza_kgf:9.2f}kgf | "
                          f"Relay={relay_status}", end='\r')
                else:
                    print(f"🚀 t={t:6.2f}s | Raw={raw:7d} | Δ={delta:7d} | "
                          f"V={ema_val:8.3f}mV | F={fuerza_kgf:9.2f}kgf | "
                          f"Relay={relay_status}", end='\r')
                
                time.sleep(0.01)
        
        # Asegurar relay apagado
        GPIO.output(RELAY_PIN, GPIO.HIGH)
        
        print(f"\n\n✅ PRUEBA COMPLETADA")
        print(f"📁 Datos guardados en: {filename}")
        print(f"⏱️  Duración: {duracion_total}s")
        
    except KeyboardInterrupt:
        GPIO.output(RELAY_PIN, GPIO.HIGH)
        print(f"\n\n⚠️  PRUEBA INTERRUMPIDA (Ctrl+C)")
        print(f"📁 Datos parciales en: {filename}")
    except Exception as e:
        GPIO.output(RELAY_PIN, GPIO.HIGH)
        print(f"\n\n❌ ERROR: {e}")
        print(f"📁 Datos parciales en: {filename}")
    
    input("\nPresiona ENTER para continuar...")

# ==============================
# MENÚ PRINCIPAL
# ==============================
def menu_principal():
    """Menú principal del sistema"""
    while True:
        print("\n" + "="*60)
        print("🔬 SISTEMA DE BANCO DE PRUEBAS - THRUST TEST")
        print("="*60)
        
        # Mostrar config actual
        config = load_config()
        print(f"\n📊 Configuración actual:")
        print(f"   GAIN: {config['GAIN']}")
        print(f"   SPS: {config['DRATE']}")
        print(f"   Factor calibración: {config['calibration_factor']:.6f} kg/mV")
        print(f"   Tare: {config['raw_zero']}")
        
        print("\n" + "="*60)
        print("1. 🔧 MODO CALIBRACIÓN")
        print("2. 🚀 MODO PRUEBA (con ignición)")
        print("3. ❌ SALIR")
        print("="*60)
        
        opcion = input("\nSelecciona opción: ").strip()
        
        if opcion == "1":
            modo_calibracion()
        elif opcion == "2":
            modo_prueba()
        elif opcion == "3":
            print("\n👋 Saliendo del sistema...")
            break
        else:
            print("❌ Opción inválida")

# ==============================
# MAIN
# ==============================
if __name__ == "__main__":
    try:
        menu_principal()
    except KeyboardInterrupt:
        print("\n\n⚠️  Sistema interrumpido")
    except Exception as e:
        print(f"\n\n❌ ERROR FATAL: {e}")
    finally:
        try:
            GPIO.output(RELAY_PIN, GPIO.HIGH)  # Seguridad
            print("🔒 Relay asegurado en OFF")
        except:
            pass
        GPIO.cleanup()
        print("✅ GPIO liberado - Sistema cerrado de forma segura")

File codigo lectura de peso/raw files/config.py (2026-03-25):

# /*****************************************************************************
# * | File        :	  EPD_1in54.py
# * | Author      :   Waveshare team
# * | Function    :   Hardware underlying interface
# * | Info        :
# *----------------
# * |	This version:   V1.0
# * | Date        :   2019-01-24
# * | Info        :   
# ******************************************************************************/
# Permission is hereby granted, free of charge, to any person obtaining a copy
# of this software and associated documnetation files (the "Software"), to deal
# in the Software without restriction, including without limitation the rights
# to use, copy, modify, merge, publish, distribute, sublicense, and/or sell
# copies of the Software, and to permit persons to  whom the Software is
# furished to do so, subject to the following conditions:
#
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


import spidev
import RPi.GPIO as GPIO
import time

# Pin definition
RST_PIN         = 18
CS_PIN       = 22
DRDY_PIN        = 17

# SPI device, bus = 0, device = 0
SPI = spidev.SpiDev(0, 0)

def digital_write(pin, value):
    GPIO.output(pin, value)

def digital_read(pin):
    return GPIO.input(DRDY_PIN)

def delay_ms(delaytime):
    time.sleep(delaytime // 1000.0)

def spi_writebyte(data):
    SPI.writebytes(data)
    
def spi_readbytes(reg):
    return SPI.readbytes(reg)
    

def module_init():
    GPIO.setmode(GPIO.BCM)
    GPIO.setwarnings(False)
    GPIO.setup(RST_PIN, GPIO.OUT)
    GPIO.setup(CS_PIN, GPIO.OUT)
    #GPIO.setup(DRDY_PIN, GPIO.IN)
    GPIO.setup(DRDY_PIN, GPIO.IN, pull_up_down=GPIO.PUD_UP)
    SPI.max_speed_hz = 20000
    SPI.mode = 0b01
    return 0;

### END OF FILE ###

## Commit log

2026-03-25 me equivoque
    meti la carpeta que no era
    [00 Assem sim1.SLDASM, 00 Assem sim2.SLDASM, 01 Assem sim1 STEP.SLDASM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]
2026-03-27 Cambio de estado de pines
    Cambie el estado de pines para que se active el rele
